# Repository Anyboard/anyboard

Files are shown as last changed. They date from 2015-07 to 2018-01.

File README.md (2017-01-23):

# Anyboard: A platform for making and play hybrid board games

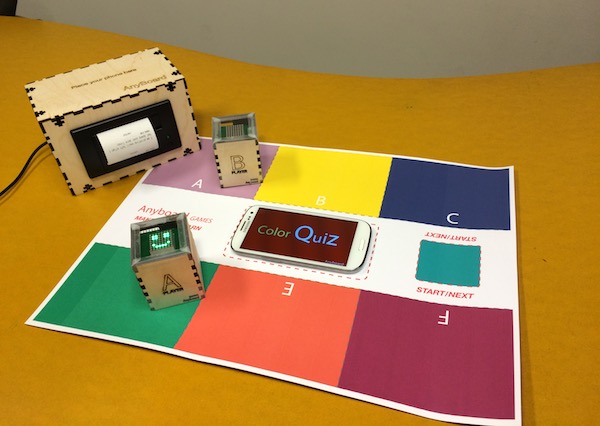
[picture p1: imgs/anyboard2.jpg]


Making hybrid board games that mix the interactivity of video games with the social impact of board games is challenging. While the design process needs to take into account elements from the digital and analog domains, building prototypes requires dealing with diverse technologies in the field of Tangible Interfaces and Interactive Tabletop and Surfaces. 

*Anyboard* is an innovative platform to make and play hybrid board games. Anyboard games blend the social impact of traditional board games with the interactivity of video games. 

Our platform provides theoretical tools to map traditional board game interaction to the hybrid medium and lightweight technology tools to facilitate game prototyping. Our platform provides augmented game pieces that work with traditional cardboards, allowing designers to easily build collaborative interactive games without requiring engineering skills.

For furter references and details please read:
S. Mora, T. Fagerbekk, M. Monnier, E. Schroeder and M. Divitini. “Anyboard: a Platform for Hybrid Board Games”. In proceedings of the International Conference on Entertainment Computing (ICEC), 2016. [preprint](https://dl.dropboxusercontent.com/u/4495822/Papers/Papers/Anyboard_ICEC_preprint.pdf)

Anyboard is released under [Apache 2.0 license](https://tldrlegal.com/license/apache-license-2.0-(apache-2.0)).

# Anyboard fundamentals

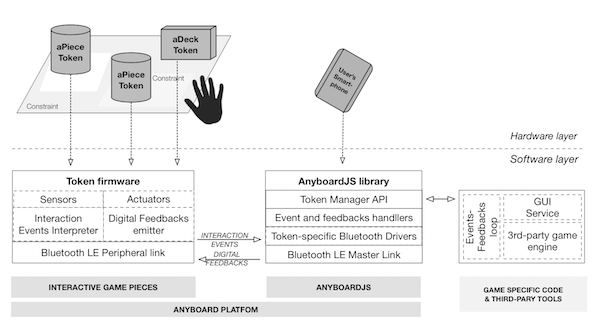
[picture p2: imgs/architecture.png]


The platform supports the development of interactive board games with design and prototyping tools. 

- Anyboard *Design Entities* help modelling players' interaction with technology-augmented game pieces, facilitating mapping game rules with mechanics and helping the transition between design and implementation. 
- Anyboard software and hardware tools support prototype development with 
  1. *Interactive game tokens and cardboard templates* to support the construction of the game hardware. The tokens are generic enough to be reused across different games
  2. *AnyboardJS* A software library to facilitate the coding of games by abstracting the complexity of dealing with hardware and lowlevel programming. The library is designed to be packaged as smartphone app. Rather than being a primary means of interaction, in our platform the smartphone runs the game engine and provide an administration interface. 
  
## Design entities
  
Anyboard Design entities constitute the foundation of a language to model interaction styles with hybrid board games. They are derived from the [ITo approach](http://link.springer.com/chapter/10.1007/978-3-319-26005-1_10) and are mapped to traditional board game elements.

| Anyboard Design Entities | Traditional Board Game Elements |
|:---:|:---:|
| Tokens | Game Pieces |
| Constraints | Board tiles or sockets |
| Interaction Events | Player's actions |

- *Tokens* are technology-augmented artifacts which resemble traditional game pieces; ranging from elements of chance (e.g. an augmented dice in *Backgammon* or RFID-enabled cards in *Monopoly*) to game pieces, e.g. pawns augmented with an LCD displaying the player’s rank in the game.
- *Constraints* are either visual or physical confining regions in the board space. The association or dissociation of a token within a constraint can be mapped to digital operations to activate game dynamics. Examples of constraints are checks for Chess pieces and territories in Risk.
- *Interaction events* are player-triggered manipulations of tokens, that mod- ify the (digital and physical) state of a game. We define three types of events:
  * *Token Event (TE)*: the manipulation of a single token on, over around the board; e.g. the action of rolling a dice or drawing a card
  * *Token-Constraint Event (TCE)*: the operation of building transient token- constraint associations by adding or removing tokens to a constrained region of the board; e.g. moving army pieces beyond a territory line as an attack action
  * *Token-Token Event (TTE)*: the operation of building transient token-token adjacency relationships, achieved by moving tokens on the board; e.g. moving a token next to another token to exchange a resource between two players.

An Anyboard game can be therefore defined as a sequence of player-initiated interaction events that modify spatial configurations of tokens with respect to board constraints and other tokens. As a consequence tokens’ intangible (digital feedbacks) representations are updated.
Sequences of interaction events describe players’ actions during the game and are mapped to specific game dynamics implemented in a game engine.
The game engine connects and exchange data with tokens using the AnyboardJS library running on the user’s smartphone, for example activating specific game mechanics according with interaction events sensed by tokens or triggering digital feedbacks.

## Intearactive game tokens and cardboard template

Anyboard currently prototypes two different types of interactive tokens: aPawn, an augmented game piece, and aDeck, an augmented card deck. Being two of the most common elements of board game they can be used to implement a wide range of games.

### anyPawn

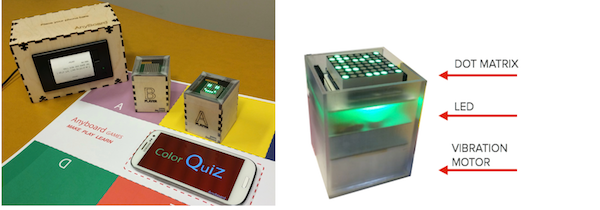
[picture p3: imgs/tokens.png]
aPawn


*aPawns* are a technology-augmented version of pawn pieces commonly found in most games. They are capable of capturing the set of interaction events and produce digital feedbacks. More information: [anyPawn page](./anypawn).

### anyDeck

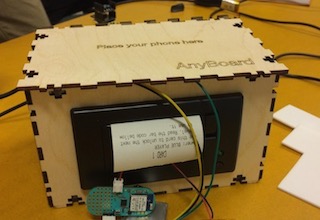
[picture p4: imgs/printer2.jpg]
aDeck


*aDeck* is an interactive version of the card deck commonly found in board games. Instead of holding stacks of cards, aDeck prints out its own cards using a small thermal printer. More information: [anyDeck page](./anydeck)

### Cardboard templates

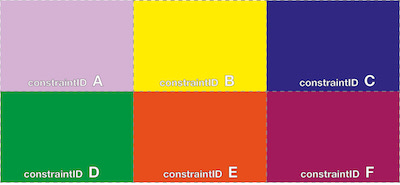
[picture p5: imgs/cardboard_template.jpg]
cardboard_template


The cardboard template provides support to create custom cardboards that interact with aPawn tokens. aPawns use color temperature sensing to implement constraint regions. We therefore selected nine colors that provided satisfactory sensor recognition rate across different materials and printing techniques and associate them with unique IDs to be used in game development. A color palette to draw cardboard with custom constraint regions is provided as a template file that can be modified with vector graphic editors. More information: [Cardboard templates](./cardboard-templates)

## AnyboardJS library

AnyboardJS library is a javascript library providing developer-friendly interface between the interactive tokens pand game-specific code developed with or without third-party game engines and running in a smartphone app. 

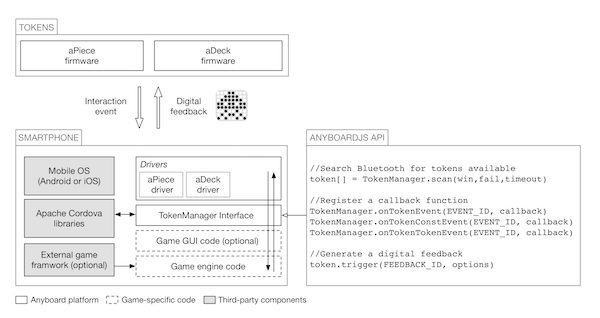
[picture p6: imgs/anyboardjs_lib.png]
AnyboardJS


AnyboardJS provides two main functions. 

1. It establishes wireless links with aPawn and aDeck enabling data exchange using specific drivers for each type of token. 
2. It provides a TokenManager interface to enable developers to easily write javascript code to handle interaction events from tokens and generate digital feedbacks, to implement game-specific routines. The library is designed to be extensible, support to new interactive tokens can be added by writing driver modules. 

Although tokens are the primary user interface with a game, it is possible to code a secondary GUI to display extended informaion and controls on the smartphone screen; e.g. to be used to edit game settings, to display game rules and leader-boards. This functionality can be implemented with external libraries (e.g. jQuery mobile1).

A subset of the TokenManager interface functions is provided in Figure. More information: [AnyboardJS page](./anyboardJS)

# How to make an Anyboard Game

TBD

# Example games

See [Games page](./games).

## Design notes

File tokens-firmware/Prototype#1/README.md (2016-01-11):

## Token Specs Prototype#1

### Pawn

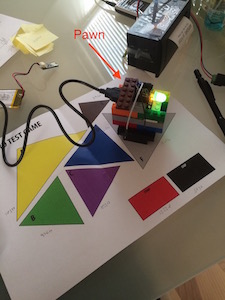
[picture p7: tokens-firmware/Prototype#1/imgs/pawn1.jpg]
pawn front pawn 1

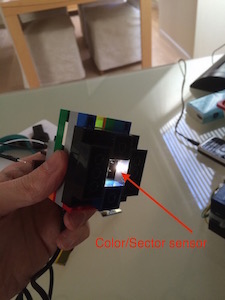
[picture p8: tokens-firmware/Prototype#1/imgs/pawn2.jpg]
pawn front pawn 2


#### Hardware
* [RFDUINO](http://www.rfduino.com)
* RGB Color Sensor - [specs](https://www.adafruit.com/products/1356) - [tutorial](https://learn.adafruit.com/adafruit-color-sensors) 
* RGB LED
* 850Mha LiPo Battery

#### Software
* Arduino IDE
* Arduino JSON - [link](https://github.com/bblanchon/ArduinoJson)
* Color Sensor Library - [link](https://github.com/adafruit/Adafruit_TCS34725)

### Printer

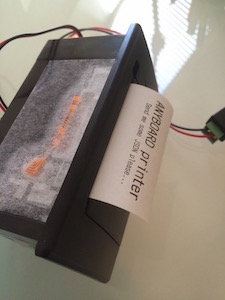
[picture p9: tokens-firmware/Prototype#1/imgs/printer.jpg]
printer front


#### Hardware
* [Bean](http://legacy.punchthrough.com/bean/) *Temporaney, this will be replaced by RFDUINO*
* Mini Thermal Printer - [specs](https://www.adafruit.com/products/597) - [tutorial](https://learn.adafruit.com/mini-thermal-receipt-printer)
* Power adapter

#### Software
* Arduino IDE
* Arduino JSON - [link](https://github.com/bblanchon/ArduinoJson)
* Adafruit Thermal_Library - [link](https://github.com/adafruit/Adafruit-Thermal-Printer-Library)

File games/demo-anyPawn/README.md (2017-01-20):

# Anyboard Demo App

Demonstrates the basic functioning of the Anyboard Pawn and Printer

## Setup

### Required hardware

- Anybaord Pawn

### Download and install Evothings
- Install [Evothings](https://evothings.com/download/) on your PC/Mac
- Install [Evothings](https://evothings.com/download/) app on your phone.

### Connect to Evothings
- Open Evothing on your PC
- Drag the index.html file into [Evothings](http://evothings.com) workbench.
- Open Evothings app on your phone
- Connect to workbench running on PC
- Run the example app from Evothings Workbench

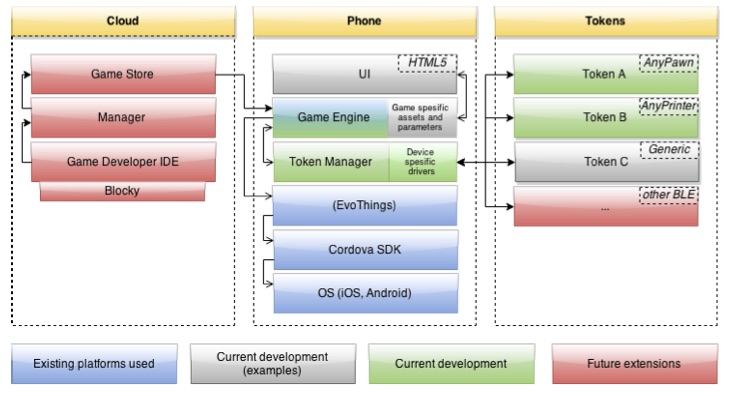
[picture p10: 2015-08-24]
tokens-firmware/Prototype#1/imgs/architecture.jpg

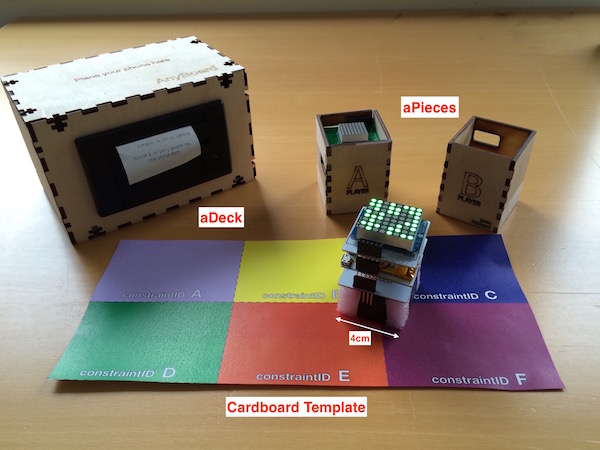
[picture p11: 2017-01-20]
imgs/anyboard.jpg

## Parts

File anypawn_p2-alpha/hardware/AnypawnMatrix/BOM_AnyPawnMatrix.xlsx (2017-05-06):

Bill Of Materials for
Design Title |  |  | AnyPawMatrix
Author |  |  | Théo HYVON
Document Number |  |  | 1
Revision |  |  | 1
Design Created |  |  | vendredi 31 mars 2017
Design Last Modified |  |  | mardi 4 avril 2017
Total Parts In Design |  |  | 6
 |  |  |  |  |  |  |  | Totals
Category | Quantity | References | Value | PCB Package | Fournisseur | Prix | Réf. Fournisseur | Category | Quantity
Condensateurs | 1 | C1 | 220nF | 0603 | Mouser | 0,17 | 581-06036C224MAT2A | Condensateurs | 1
Résistances | 2 | R1-R2 | 10k | 0805 | X | X | X | Résistances | 2
Circuits integrés | 1 | U1 | KWM-30881 | KWM-30881 | Mouser | 4,67 | 485-1623 | Circuits integrés | 2
Circuits integrés | 1 | U2 | HT16K33 | SOP24 |  |  |  | Connecteurs | 1
Connecteurs | 1 | J3-Female | SWD_STM32 CONNECT | SWD_STM32 CONNECT | Mouser | 0,24 | 710-653005113322
Connecteurs | 1 | J3 | SWD_STM32 CONNECT | SWD_STM32 CONNECT | Mouser | 1,8 | 710-653105124022
 |  |  |  |  |  |  |  | Total | 6

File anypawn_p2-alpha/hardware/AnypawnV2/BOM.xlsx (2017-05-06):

Bill Of Materials for AnyPawn
Design Title |  |  | AnyPawn |  | Total Price | 68.00 €
Author |  |  | Théo HYVON
Document Number
Revision |  |  | 1.0
Design Created |  |  | lundi 20 mars 2017
Design Last Modified |  |  | mardi 4 avril 2017
Total Parts In Design |  |  | 95
 |  |  |  |  |  |  |  |  | Totals
Category | Quantity | References | Value | PCB Package | Fournisseur | Prix | Réf. Fournisseur |  | Category | Quantity
Condensateurs | 8 | C1-C8 | 1nF | 0805 | Mouser | 0,885 | 767-0805B102J102NT | 7.08 € | Condensateurs | 25
Condensateurs | 5 | C10,C14,C16-C17,C24 | 10uF | 0805 | Mouser | 0,141 | 81-GRM219R60J106KE9D | 0.70 € | Circuits integrés | 11
Condensateurs | 3 | C9, C11, C12 | 220nF | 0603 | Mouser | 0,17 | 581-06036C224MAT2A | 0.51 € | Diodes | 7
Condensateurs | 7 | C13,C15,C18-C20,C23,C25 | 100nF | 0603 | Mouser | 0,094 | 81-GRM188R70J104KA1D | 0.66 € | Inductances | 7
Condensateurs | 2 | C21-C22 | 47pF | 0402 | Mouser | 0,141 | 581-06036A470JAT2A | 0.28 € | Miscellaneous | 15
Résistances | 4 | R1,R5,R9,R13 | 220k | 0603 | Mouser | 0,104 | 755-ESR03EZPF2203 | 0.42 € | Total | 95
Résistances | 5 | R2,R6,R10,R14,R21 | 1k | 0603 | Mouser | 0,104 | 755-KTR03EZPJ102 | 0.52 €
Résistances | 13 | R3-R4,R7-R8,R11-R12,R15-R17,R19-R20,R22,R29 | 10k | 0603 | Mouser | 0,104 | 755-ESR03EZPF1002 | 1.35 €
Résistances | 1 | R18 | 100 | 0603 | Mouser | 0,179 | 71-CRCW0603100RFKEAH | 0.18 €
Résistances | 2 | R23-R24 | 27 | 0402 | Mouser | 0,094 | 667-ERJ-2RKF27R0X | 0.19 €
Résistances | 3 | R25-R26,R28 | 510 | 0603 | Mouser | 0,095 | 652-CR0603FX-5100ELF | 0.29 €
Résistances | 1 | R27 | 2k | 0603 | Mouser | 0,094 | 71-CRCW0603-2.0K-E3 | 0.09 €
Résistances | 1 | R31 | 47k | 0603 | Mouser | 0,113 | 755-KTR03EZPF4702 | 0.11 €
Circuits integrés | 2 | U1-U2 | LM358 | TSSOP8 | Mouser | 0,349 | 511-LM358DT | 0.70 €
Circuits integrés | 1 | U3 | CY8C4245LQI-483 | CY-QFN40-6X6-NOCP | Mouser | 3,17 | 727-CY8C4245LQI-483 | 3.17 €
Circuits integrés | 1 | U4 | TCS34725 | TCS32725 | Mouser | 2,49 | 985-TCS34725FN | 2.49 €
Circuits integrés | 1 | U5 | VL6180X | VL6180X | Mouser | 4,49 | 511-VL6180XV0NR/1 | 4.49 €
Circuits integrés | 1 | U6 | TPS63001 | PVSON-N10 | Mouser | 2,12 | 595-TPS63001DRCR | 2.12 €
Circuits integrés | 1 | U7 | TPS79028 | SOT95P280X145-5A | Mouser | 1,25 | 595-TPS79028DBVR | 1.25 €
Circuits integrés | 1 | U8 | FTD231X | QFN-20 | Mouser | 2 | 895-FT231XQ-R | 2.00 €
Circuits integrés | 1 | U9 | MCP73831 | SOT23-5 | Mouser | 0,566 | 579-MCP73831T-2ACIOT | 0.57 €
Circuits integrés | 1 | U10 | SIMBLEE | SIMBLEE | Mouser | 17,11 | 975-RFD77101 | 17.11 €
Circuits integrés | 1 | U11 | LSM9DS0 | LGA-24 4X4X1MM | Digikey | 6,87 | 497-13902-1-ND | 6.87 €
Diodes | 1 | D1 | CLM3C-WKW-CWBYA453 | CREE_LED_WHITE | Mouser | 0,198 | 941-CLM3CWKWCWBYA453 | 0.20 €
Diodes | 1 | D2 | ESDALC6V1 | 0402 ORIENTED | Mouser | 0,453 | 511-ESDALC6V1-1M2 | 0.45 €
Diodes | 1 | D3 | LED_CMS | LEDC1608X60 | Mouser | 0,339 | 720-LGQ396A3964 | 0.34 €
Diodes | 1 | D4 | LED_CMS | LEDC1608X60 | Mouser | 0,189 | 755-SML-D12U1WT86 | 0.19 €
Diodes | 1 | D5 | LED_CMS | LEDC1608X60 | Mouser | 0,33 | 755-SMLE13BC8TT86 | 0.33 €
Diodes | 1 | D6 | 1N4148WS-7 | SOD2514X100 | Mouser | 0,16 | 621-1N4148WS-F | 0.16 €
Diodes | 1 | D7 | NEOPIXEL SK6812 | NEOPIXEL | Mouser | 4,24 | 485-1655 | 4.24 €
Inductances | 4 | L1-L4 | 330uH | IND_5.8_BOURNS | Mouser | 0,445 | 652-SDR0604-221KL | 1.78 €
Inductances | 1 | L5 | 2.2uH | IND_ASPI2512 | Mouser | 0,358 | 815-ASPI25122R2MT2 | 0.36 €
Inductances | 2 | L6-L7 | LI0402E300R-10 | 0402 | Mouser | 0,1 | 875-LI0402E300R-10 | 0.20 €
Miscellaneous | 1 | J1 | USBCONN | CONN USB B MICRO | Mouser | 0,868 | 490-UJ2-MIBH2-4-SMT | 0.87 €
Miscellaneous | 1 | J2 | SIL-100-02 | CONN-SIL2 | X | 0 | X | 0.00 €
Miscellaneous | 1 | J3 | CONN-SIL5 | CONN-SIL5 | X | 0 | X | 0.00 €
Miscellaneous | 1 | J4-Female | JX | SWD_STM32 CONNECT | Mouser | 0,24 | 710-653005113322 | 0.24 €
Miscellaneous | 1 | J4 | JX | SWD_STM32 CONNECT | Mouser | 1,8 | 710-653105124022 | 1.80 €
Miscellaneous | 1 | J5 | Battery | CONN-SIL2 | X | 0 | X | 0.00 €
Miscellaneous | 5 | Q1-Q4,Q7 | BC847B | SOT23 | Mouser | 0,151 | 757-TBC847BLM | 0.76 €
Miscellaneous | 2 | Q5-Q6 | BSS138 | SOT23 | Mouser | 0,198 | 512-BSS138 | 0.40 €
Miscellaneous | 1 | SW1 | 506-MLL1200S | SPDT SLIDE SWITCH | Mouser | 2,17 | 506-MLL1200S | 2.17 €
Miscellaneous | 2 | VR1-VR2 | CG0402MLA-5.5MG | 0402 | Mouser | 0,189 | 652-CG0402MLA-5.5MG | 0.38 €

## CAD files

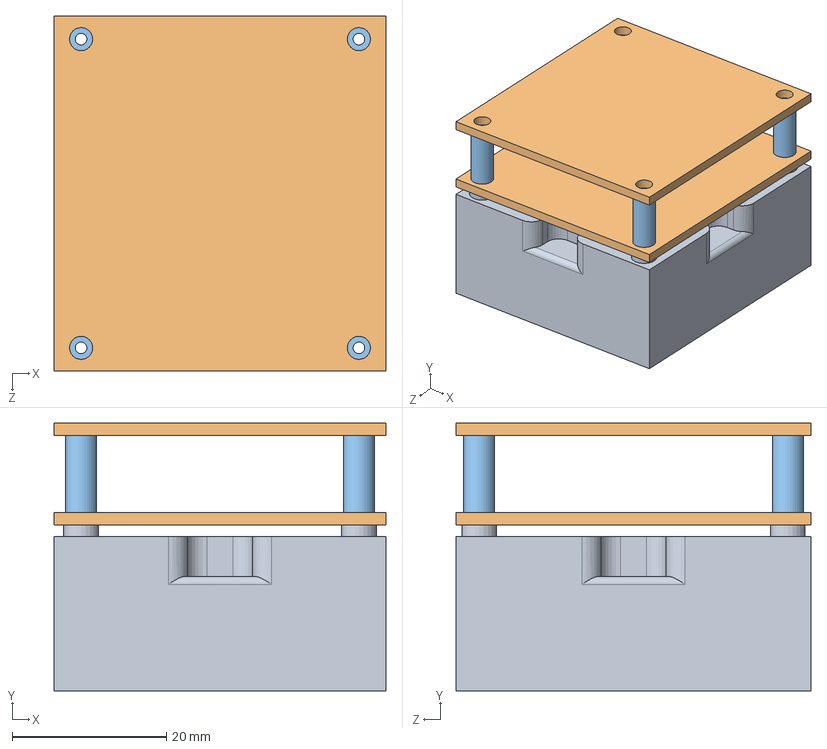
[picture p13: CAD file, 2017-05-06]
anypawn_p2-alpha/case/Assemblage.SLDASM
43.0 x 34.7 x 46.0 mm
Footer
Board x 2
Spacer x 4

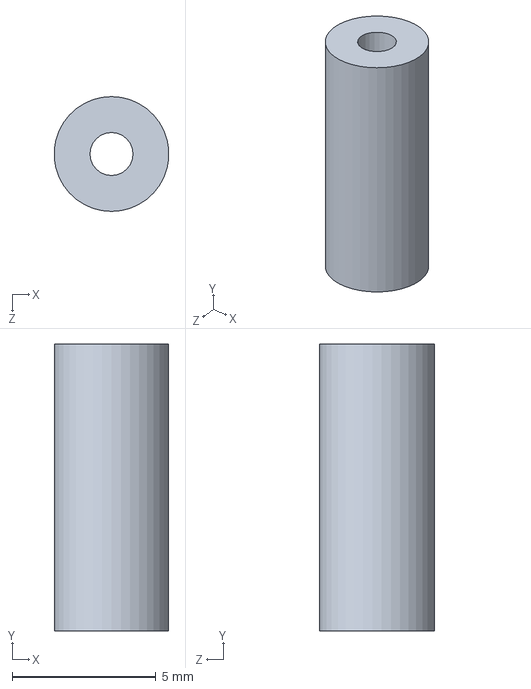
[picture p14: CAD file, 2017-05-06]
anypawn_p2-alpha/case/Spacer.SLDPRT
3.99 x 10.0 x 4.00 mm

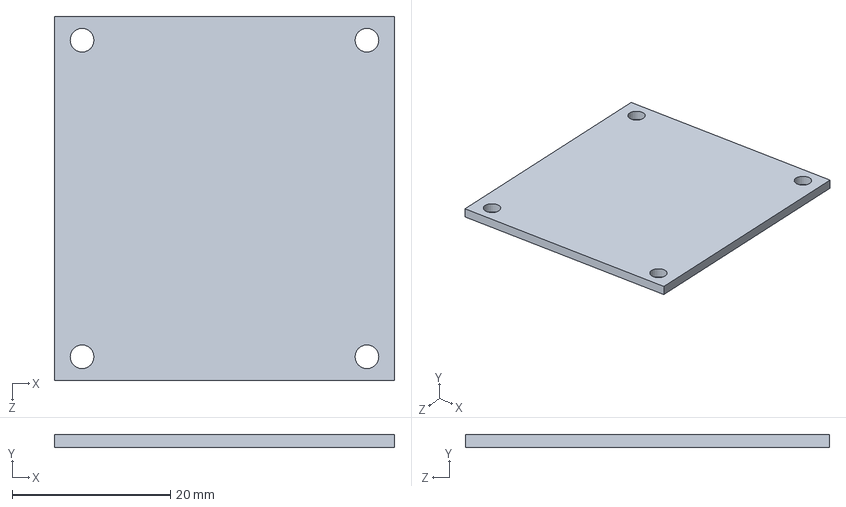
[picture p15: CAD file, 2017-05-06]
anypawn_p2-alpha/case/Board.SLDPRT
43.0 x 1.60 x 46.0 mm

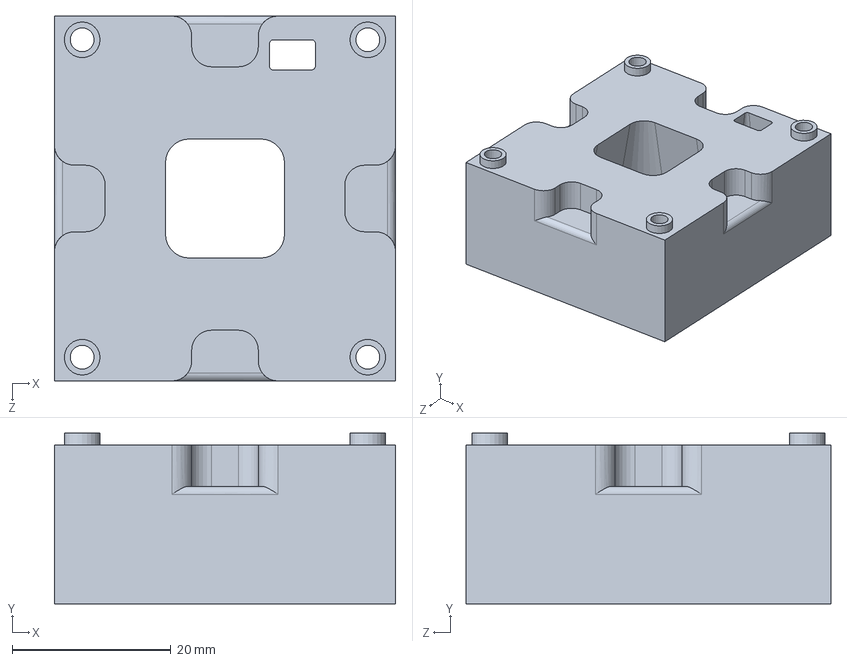
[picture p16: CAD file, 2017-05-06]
anypawn_p2-alpha/case/Footer.SLDPRT
43.0 x 21.5 x 46.0 mm

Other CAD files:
anypawn_p2-alpha/case/Spacer2.SLDPRT
anypawn_p2-alpha/case/Footer.STL

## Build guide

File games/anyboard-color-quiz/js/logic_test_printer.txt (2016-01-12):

var logic = {
    initiate: function() {
        var handleTokenMove = function(token, constraint, options) {
            AnyBoard.Logger.log(token.player + " moved to tile " + constraint);
            token.player.location = constraint;

            if (logic.everyOneHasAnswered()) {
                ui.showAnswer();
                return;
            }

            // If the token is the only one, we will not expect any Token-Token events to occur before all (1) token
            // is placed on a tile. Therefore we check if the token is the only one, and trigger the TT-event manually
            // if it is
            if (logic.numberOfConnectedTokens() === 1 && token.player.location === 2) {
                handleTokenTokenTouch(token, token);
            }
        };

        var handleTokenTokenTouch = function(initiatingToken, respondingToken, options) {
            if (respondingToken.player.location === 2) {
                hyper.log("handleTokenTokenTouch");
                if (typeof d.currentQuestionPos === "undefined") ui.activatePanel('game');
                else ui.nextQuestion();
            }
        };

        logic.addListener("game", logic.startGame);
        logic.addListener("summary", ui.finishGame);

        AnyBoard.TokenManager.onTokenConstraintEvent("MOVE_TO", handleTokenMove);
        AnyBoard.TokenManager.onTokenTokenEvent("MOVE_NEXT_TO", handleTokenTokenTouch)
    },

    // Discover bluetooth tokens in proximity
    discover: function() {
        var self = this;
        AnyBoard.TokenManager.scan(
            // success function to be executed upon _each_ token that is discovered
            function(token) {
                self.addDiscovered(token);
            },
            // function to be executed upon failure
            function(errorCode) {
                hyper.log(errorCode)
            }
        );
    },

    // Function to be executed upon having discovered a token
    addDiscovered: function(token) {
        if (!d.devices[token.address]) {
            d.devices[token.address] = token;

			if(token.name === "RFduino") {
				// Add button for token to body
				$('#setup').append('<div class="token center"><button type="button" id="' + token.address +
				'" onclick="logic.connect(' + "'" + token.address + "'" +
				')" class="grey token">' + token.name + ' </button>' +
				'<button class="player-icon' + '">&nbsp;</button>' + '</div>');

				// Add listener to be executed if the token connects
				token.on('connect', function() {
						document.getElementById(token.address).className = 'green token';
						token.color = d.colors.pop();
						token.player = new AnyBoard.Player(
							token.color + "-player",
							{
								"color": token.color,
								"points": 0,
								"locations": -1,
								"token": token
							}
						);
						d.players.push(token.player);
						$(document.getElementById(token.address)).next().addClass(token.color);
						token.ledOn(token.color);
				});

				// Add listener to be executed if the token disconnects
				token.on('disconnect', function() {
					document.getElementById(token.address).className = 'grey token';
					$(document.getElementById(token.address)).next().removeClass(token.color);
					d.colors.push(token.color);
				})
			}
			else
			{
				// Add button for token to body
                document.body.innerHTML += '<div class="token center"><button type="button" id="' + token.address + '" onclick="logic.connect(' + "'" + token.address + "'" + ')" class="grey token">' + token.name + ' </button><br />' + '</div>';

                // Add listener to be executed if the token connects
                token.on('connect', function() {
                    document.getElementById(token.adress).className = 'green token';
                });

                // Add listener to be executed if the token disconnects
                token.on('disconnect', function() {
                    document.getElementById(token.adress).className = 'red token';
                })
			}
        }
    },

    // Attempts to connect to token.
    connect: function(tokenAddress) {
        var token = d.devices[tokenAddress];

		if(token.name === "RFduino") {
			// If already connecting, stop
			if (document.getElementById(tokenAddress).className.indexOf('blue') !== -1)
				return;

			// If already connected, disconnect
			if (document.getElementById(tokenAddress).className.indexOf('green') !== -1) {
				token.disconnect();
				return;
			}
			// Signal that we're attempting to connect
			document.getElementById(tokenAddress).className = 'blue token';

			// Send connect command.
			token.connect();
		}
		else
		{
			// If already connecting, stop
			if (document.getElementById(tokenAddress).className == 'blue token')
				return;

			// If already connected, attempt to print
			if (document.getElementById(tokenAddress).className == 'green token') {
				this.print(token);
				return;
			}

			// Signal that we're attempting to connect
			document.getElementById(tokenAddress).className = 'blue token';

			// Send connect command. 
			token.connect();
		}
    },

    startGame: function(){
        hyper.log("startGame");
        d.questions = logic.shuffle(d.questions);
        d.currentQuestionPos = -1;
        ui.nextQuestion();
        for (var index in d.players) {
            if (d.players.hasOwnProperty(index))
                d.players[index].points = 0;
        }
    },

    shuffle: function(o){
        for(var j, x, i = o.length; i; j = Math.floor(Math.random() * i), x = o[--i], o[i] = o[j], o[j] = x);
        return o;
    },

    addListener: function(name, callback) {
        if (!d.listeners[name])
            d.listeners[name] = [];
        d.listeners[name].push(callback);
    },

    trigger: function(name, options) {
        hyper.log("trigger: " + name);
        if (d.listeners[name]) {
            for (var i = d.listeners[name].length - 1; i >= 0; i--) {
                d.listeners[name][i](options);
            }
        }
    },

    getCurrentQuestion: function() {
        return d.questions[d.currentQuestionPos];
    },

    getNextQuestion: function() {
        hyper.log("nextQuestion");
        d.currentQuestionPos += 1;
        if (d.currentQuestionPos >= d.questions.length) {
            return undefined; // returns undefined if no more questions left
        }
        return d.questions[d.currentQuestionPos];
    },

    givePoints: function() {
        var question = logic.getCurrentQuestion();
        for (var key in d.players) {
            if (d.players.hasOwnProperty(key)) {
                var player = d.players[key];
                var answer = player.location;
                if (question.alternatives.hasOwnProperty(answer-3)) { // '-3' because yellow = 3, green = 4...
                    if (question.alternatives[answer-3].correct)
                        player.points += 1;
                }
            }
        }
    },

    everyOneHasAnswered: function() {
        var tokenSet = AnyBoard.TokenManager.tokens;
        for (var key in tokenSet) {
            if (tokenSet.hasOwnProperty(key) && tokenSet[key].isConnected()) {
                if (tokenSet[key].player.location < 3) {
                    return false;
                }
            }
        }
        return true;
    },

    numberOfConnectedTokens: function() {
        var tokenSet = AnyBoard.TokenManager.tokens;
        var numOfConnected = 0;
        for (var key in tokenSet) {
            if (tokenSet.hasOwnProperty(key) && tokenSet[key].isConnected()) numOfConnected += 1;
        }
        return numOfConnected;
    },
	
	// Send green led command. Will only work on LightBlue Bean with a certain hardware.
    print: function(token) {
		token.print("##l##SI am printing small left align that spans over more lines##nnewLine##n##ccenter##f##f##f");
    }
};

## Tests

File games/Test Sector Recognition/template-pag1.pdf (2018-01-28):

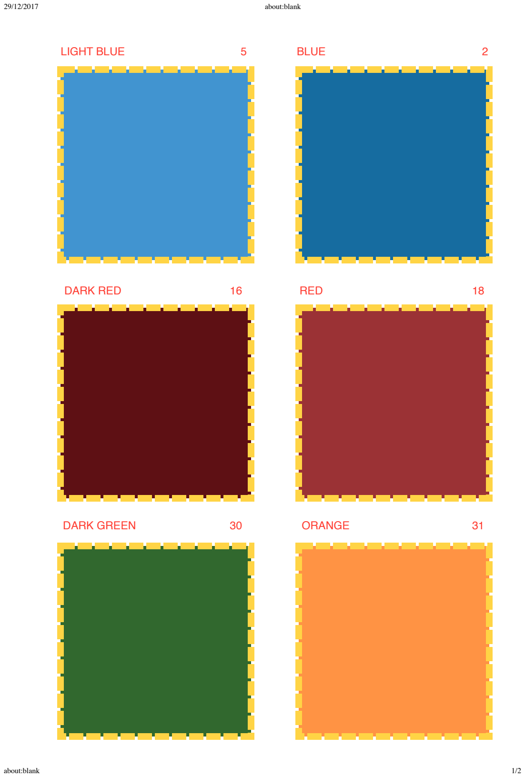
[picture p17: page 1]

29/12/2017 | about:blank
about:blank | 1/2

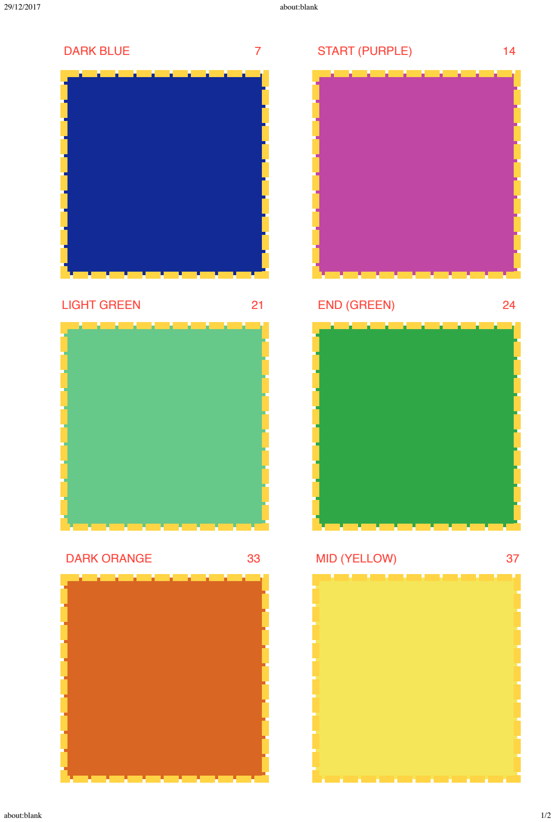
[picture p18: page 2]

29/12/2017 | about:blank
about:blank | 1/2

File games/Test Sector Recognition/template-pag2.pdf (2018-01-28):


29/12/2017 | about:blank
about:blank | 1/2

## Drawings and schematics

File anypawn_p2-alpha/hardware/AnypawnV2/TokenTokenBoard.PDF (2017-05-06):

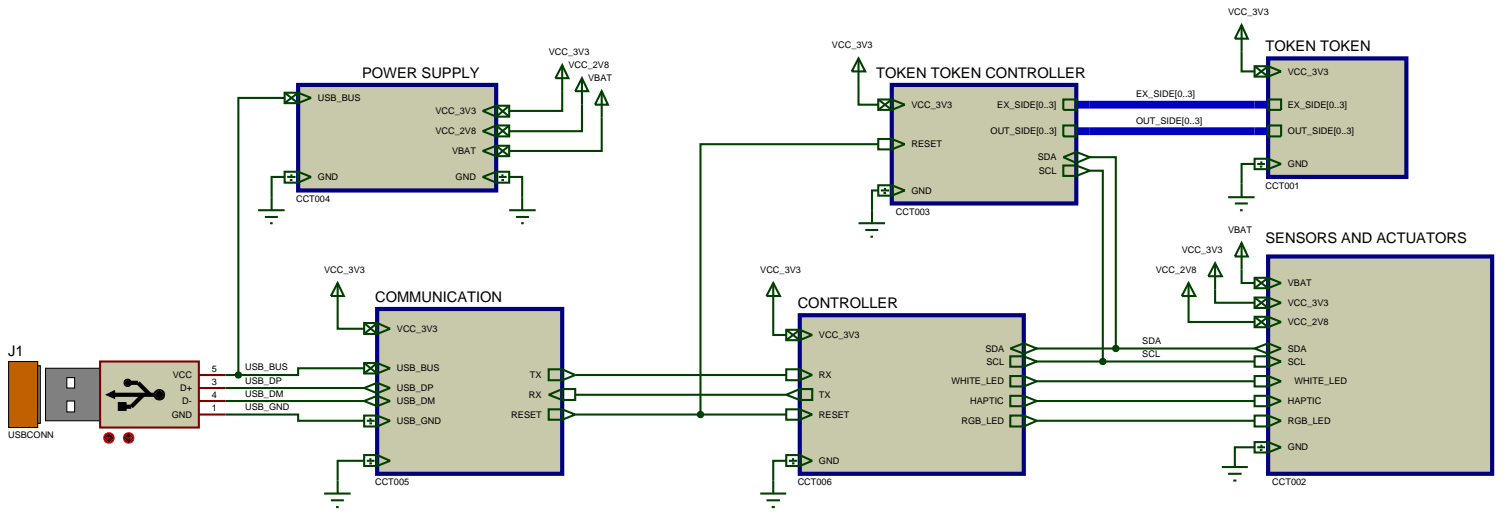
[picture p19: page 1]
Project :; DATE:; PAGE:; AnyPawn; Théo HYVON; REV:; TIME:; Sheet :; Functionnal design; OUT_SIDE[0..3]; EX_SIDE[0..3]; USB_DP USB_DM USB_GND; USB_BUS; SDA SCL; TOKEN TOKEN; CCT001; VCC_3V3; GND; CCT003; POWER SUPPLY; CCT004; CCT002; SCL; SDA; VCC_2V8; VCC_3V3 VCC_2V8; COMMUNICATION; CCT005; USB_DP USB_DM; USB_GND; RESET; VCC; USBCONN; WHITE_LED; CONTROLLER; CCT006; VBAT; HAPTIC; RGB_LED

VCC_3V3
TOKEN TOKEN CONTROLLER

VBAT
SENSORS AND ACTUATORS

U1:A

R1

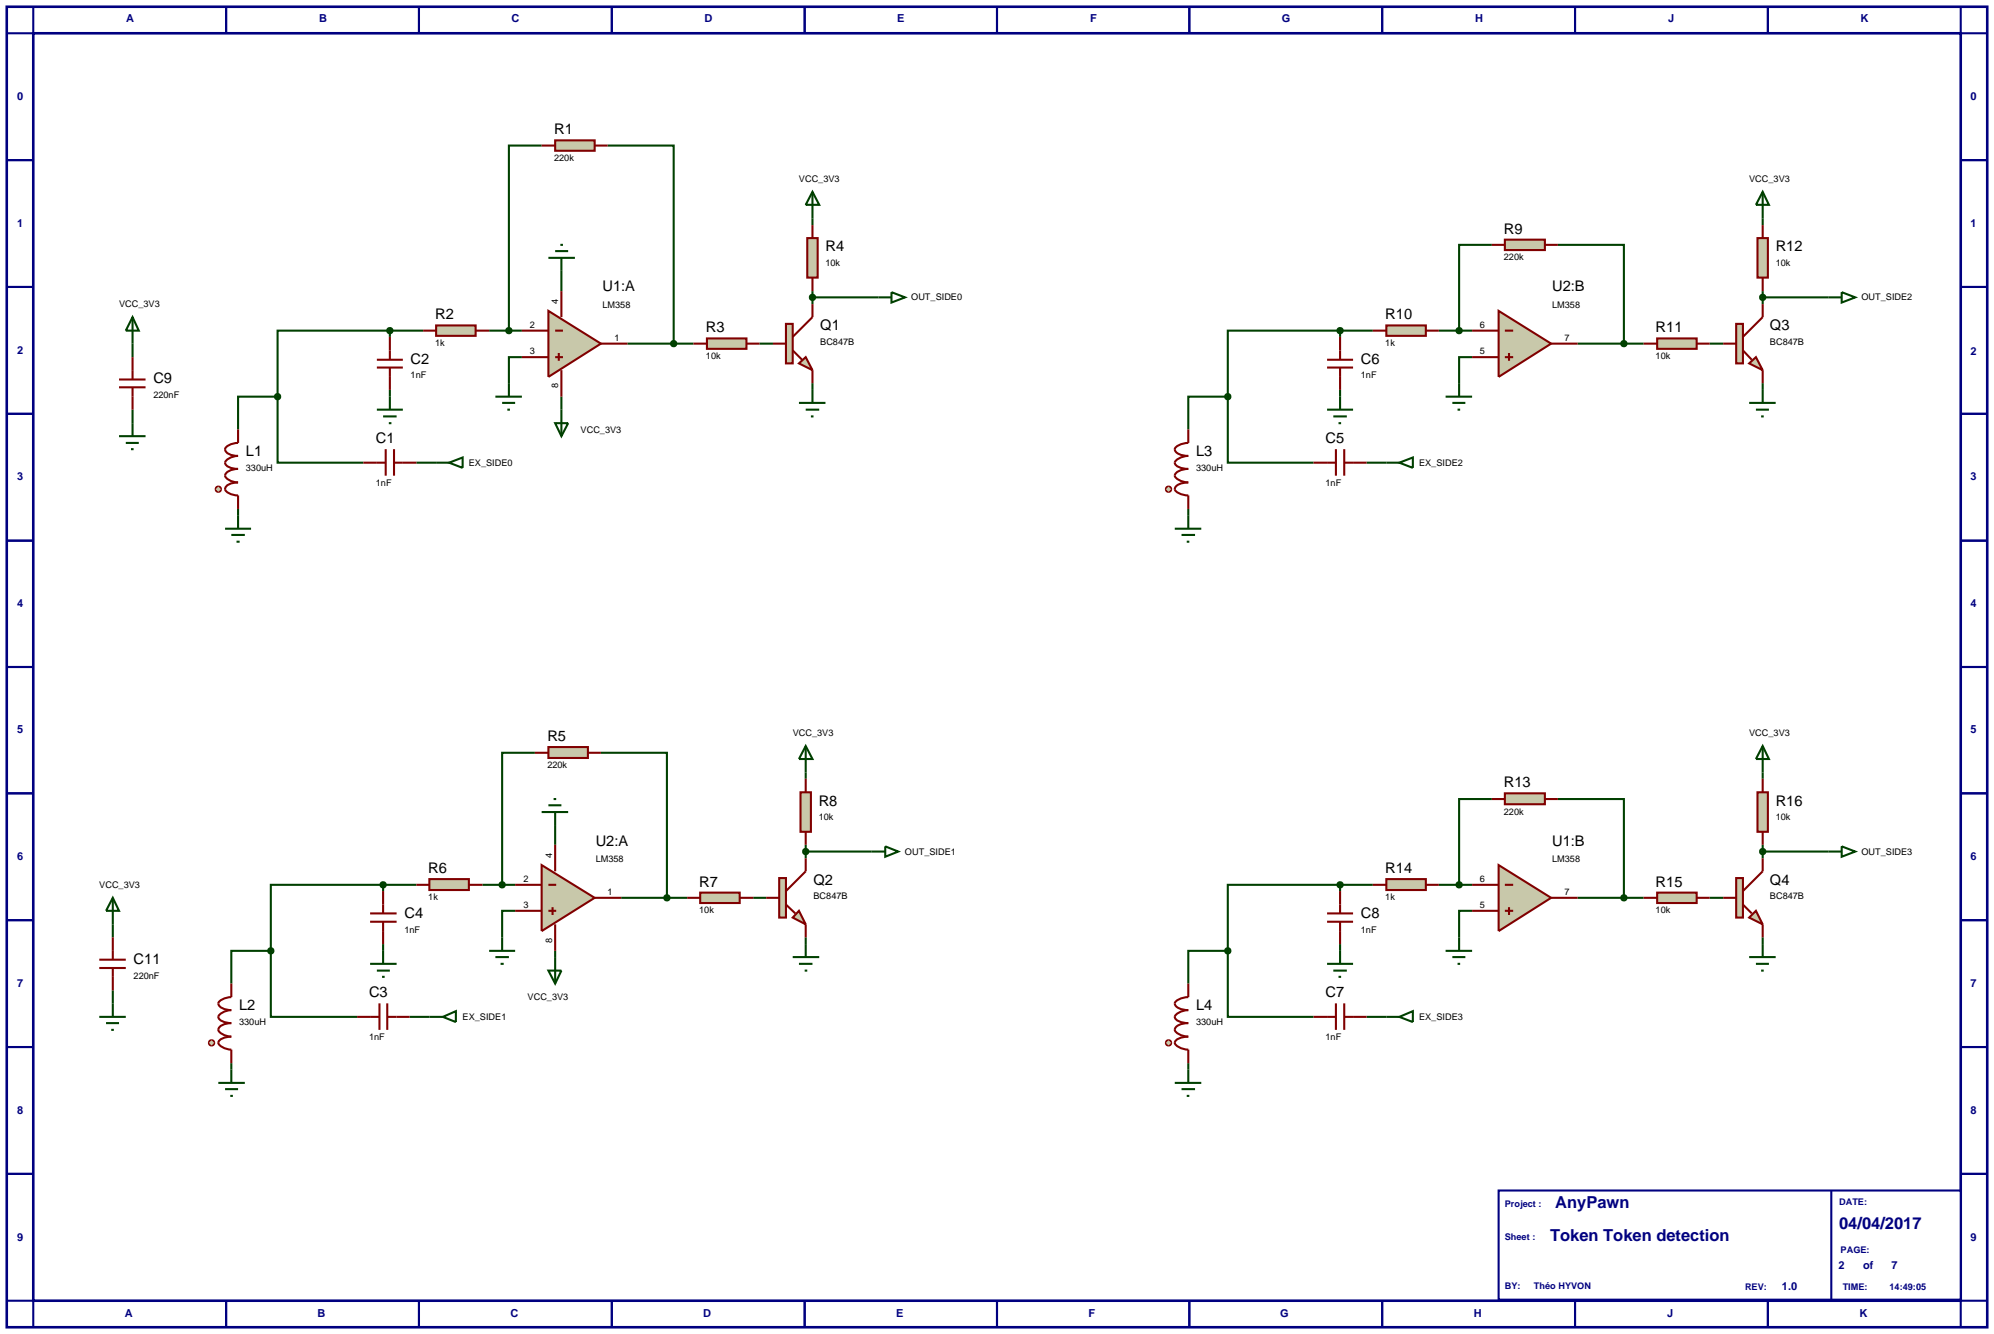
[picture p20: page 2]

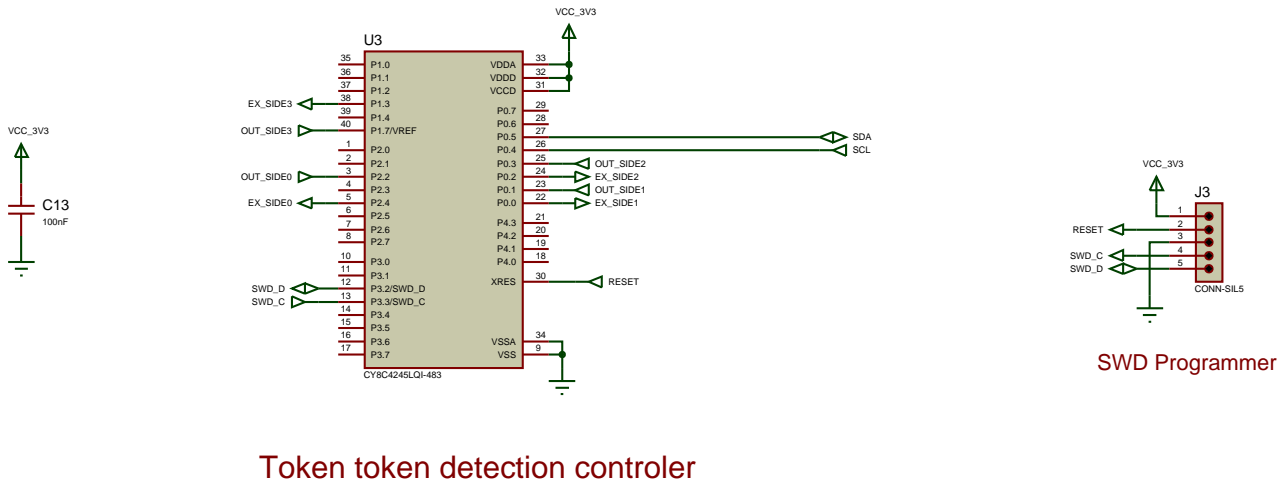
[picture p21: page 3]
Project :; DATE:; AnyPawn; Sheet :; Token Token Controller; P1.7/VREF 40; P3.1 11 P3.2/SWD_D 12 P3.3/SWD_C 13 P3.4 14; VSS; VDDD; VCCD; XRES; VSSA; VDDA; CY8C4245LQI-483; VCC_3V3; SWD_C; SWD_D; RESET; EX_SIDE0; EX_SIDE1; EX_SIDE2; EX_SIDE3; OUT_SIDE0; OUT_SIDE1; OUT_SIDE2; OUT_SIDE3; SDA; SCL; CONN-SIL5; SWD_C SWD_D; SWD Programmer

Token token detection controler

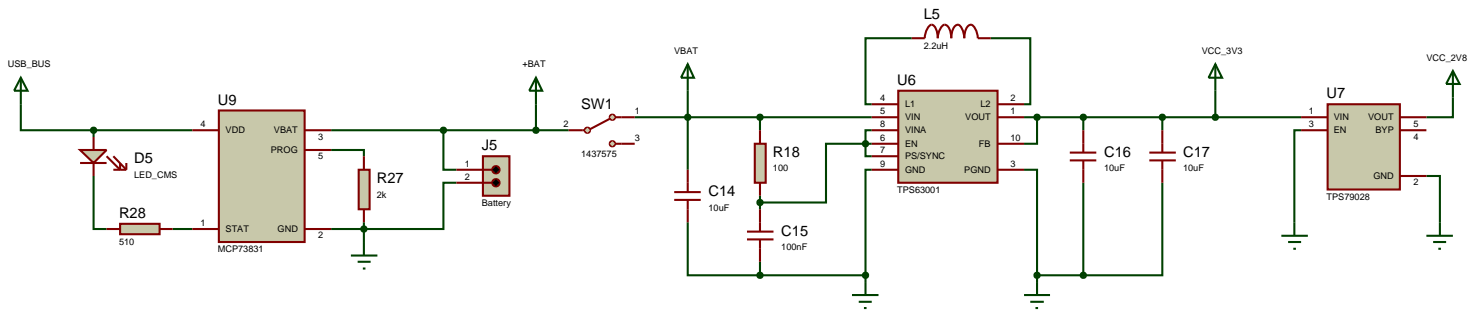
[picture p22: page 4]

U4
U5

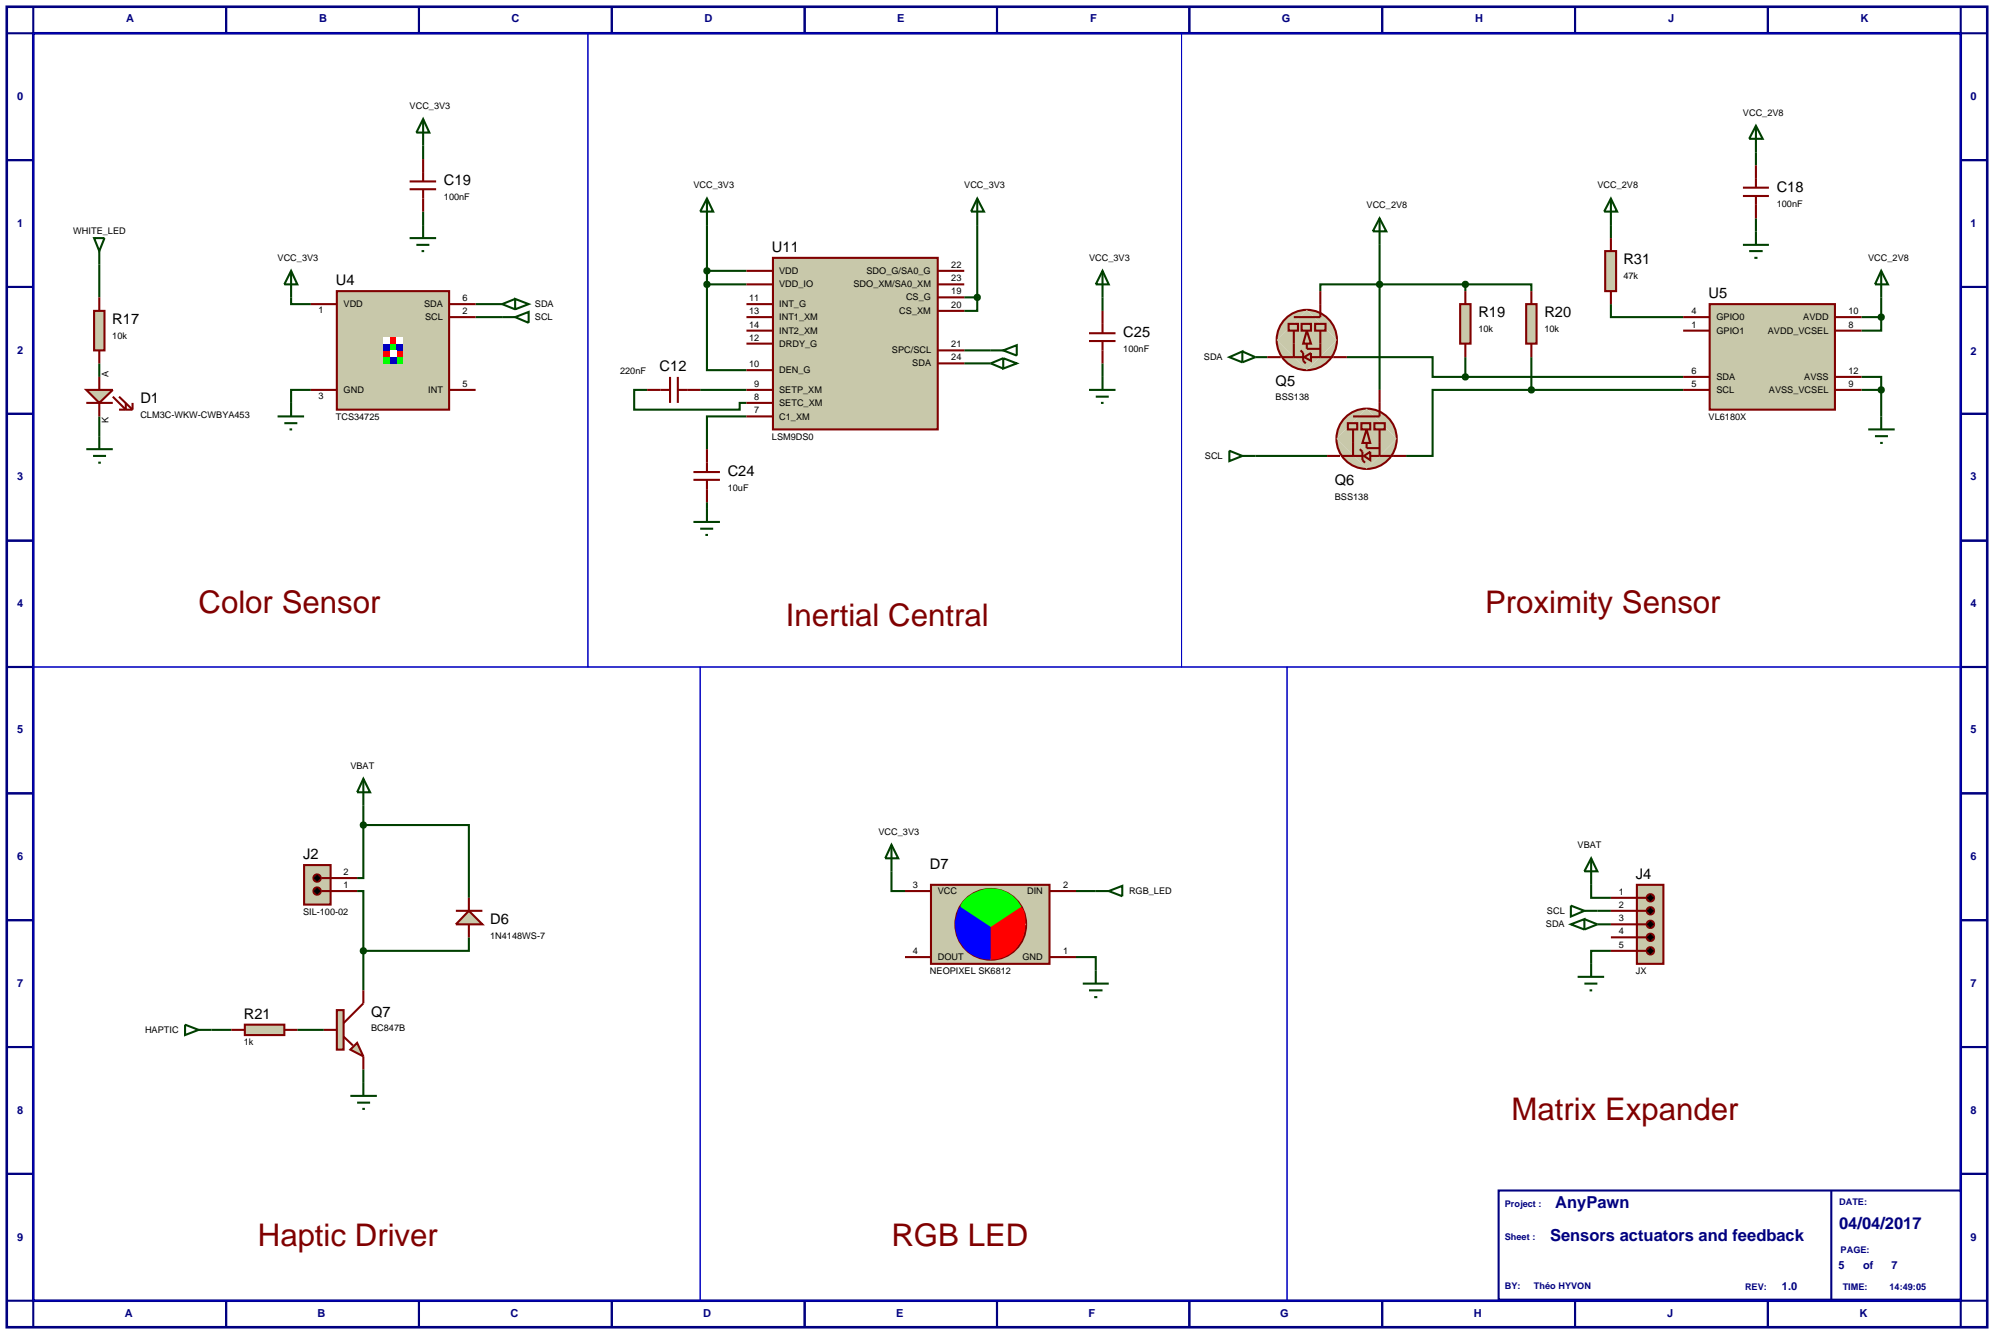
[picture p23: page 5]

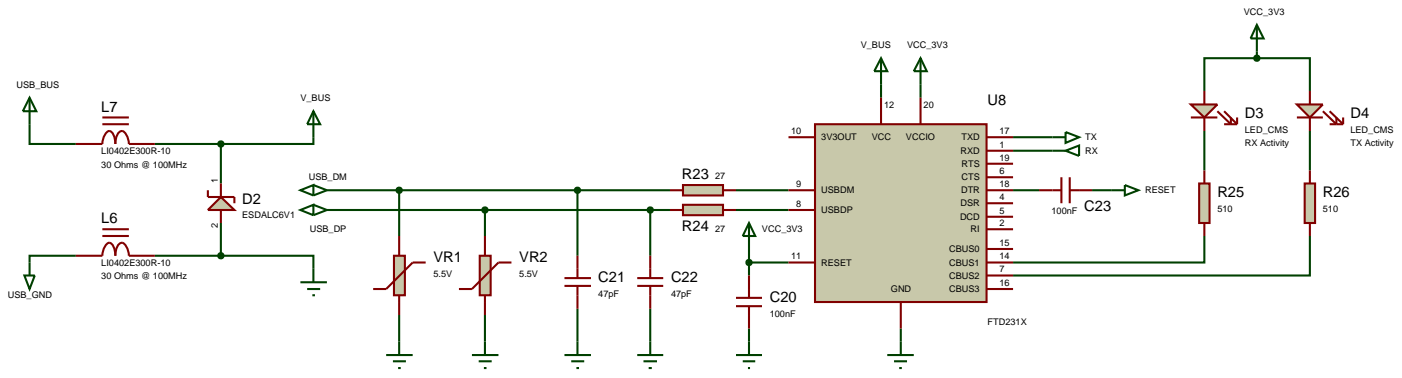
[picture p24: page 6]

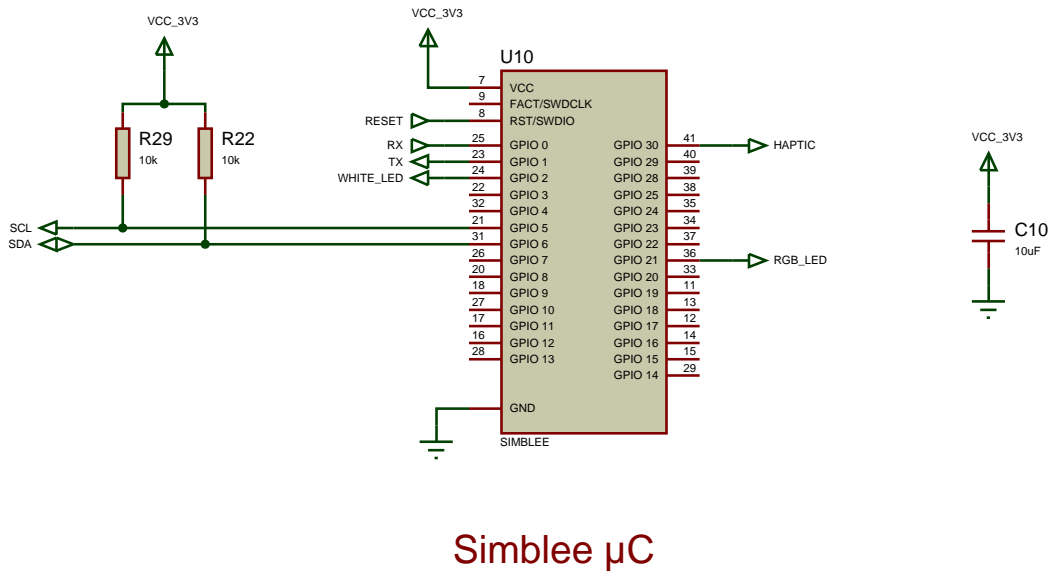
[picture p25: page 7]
Project :; DATE:; AnyPawn; Sheet :; Simblee Controler; VCC_3V3; SDA; SCL; GPIO 0 25 GPIO 1 23 GPIO 2 24 GPIO 3 22 GPIO 4 32 GPIO 5 21 GPIO 6 31 GPIO 7 26 GPIO 8 20 GPIO 9 18 GPIO 10 27 GPIO 11 17 GPIO 12 16; GPIO 30; GPIO 29; GPIO 28; GPIO 25; GPIO 24; GPIO 23; GPIO 22; GPIO 21; GPIO 20; GPIO 19; FACT/SWDCLK 9 RST/SWDIO 8; VCC 7; GND; GPIO 18; GPIO 17; GPIO 16; GPIO 15; GPIO 14; GPIO 13 28; SIMBLEE; RESET; RX TX WHITE_LED; VCC_3V3 HAPTIC; RGB_LED; Simblee µC

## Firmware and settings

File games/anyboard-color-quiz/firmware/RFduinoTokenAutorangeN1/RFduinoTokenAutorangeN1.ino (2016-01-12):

/*
 * AnyBoard Pawn firmware
 * Code based on RFduino (http://www.rfduino.com/) and
 * AdaFruit Color Sensor TCS34725 (https://www.adafruit.com/products/1334)
 *
 * Dependencies: RFduinoBLE.h and Wire.h (https://github.com/RFduino/RFduino)
 *               Adafruit_TCS34725.h (https://github.com/adafruit/Adafruit_TCS34725)
 *
 * Reference: https://cdn.sparkfun.com/datasheets/Dev/RFduino/rfduino.ble_.programming.reference.pdf
 *
 * The bean parses incoming arrays of uint8 (numbers 0-255) over bluetooth.
 *      [cmd, data, data, data etc...]
 *
 * If the cmd matches one of the COMMANDS specified, it will execute that command and respond back
 * Else it will respond 0 back
 *
 */

#include <RFduinoBLE.h>  //
#include <Wire.h>
#include "Adafruit_TCS34725.h"
#include <string.h>

//************************************************************************************************************************
// some magic numbers for this device from the DN40 application note
#define TCS34725_R_Coef 0.136 
#define TCS34725_G_Coef 1.000
#define TCS34725_B_Coef -0.444
#define TCS34725_GA 1.0
#define TCS34725_DF 310.0
#define TCS34725_CT_Coef 3810.0
#define TCS34725_CT_Offset 1391.0

// Autorange class for TCS34725
class tcs34725 {
public:
  tcs34725(void);

  boolean begin(void);
  void getData(void);  

  boolean isAvailable, isSaturated;
  uint16_t againx, atime, atime_ms;
  uint16_t r, g, b, c;
  uint16_t ir; 
  uint16_t r_comp, g_comp, b_comp, c_comp;
  uint16_t saturation, saturation75;
  float cratio, cpl, ct, lux, maxlux;
  
private:
  struct tcs_agc {
    tcs34725Gain_t ag;
    tcs34725IntegrationTime_t at;
    uint16_t mincnt;
    uint16_t maxcnt;
  };
  static const tcs_agc agc_lst[];
  uint16_t agc_cur;

  void setGainTime(void);  
  Adafruit_TCS34725 tcs;    
};
//
// Gain/time combinations to use and the min/max limits for hysteresis 
// that avoid saturation. They should be in order from dim to bright. 
//
// Also set the first min count and the last max count to 0 to indicate 
// the start and end of the list. 
//
const tcs34725::tcs_agc tcs34725::agc_lst[] = {
  { TCS34725_GAIN_60X, TCS34725_INTEGRATIONTIME_700MS,     0, 47566 },
  { TCS34725_GAIN_16X, TCS34725_INTEGRATIONTIME_154MS,  3171, 63422 },
  { TCS34725_GAIN_4X,  TCS34725_INTEGRATIONTIME_154MS, 15855, 63422 },
  { TCS34725_GAIN_1X,  TCS34725_INTEGRATIONTIME_2_4MS,   248,     0 }
};
tcs34725::tcs34725() : agc_cur(0), isAvailable(0), isSaturated(0) {
}

// initialize the sensor
boolean tcs34725::begin(void) {
  tcs = Adafruit_TCS34725(agc_lst[agc_cur].at, agc_lst[agc_cur].ag);
  if ((isAvailable = tcs.begin())) 
    setGainTime();
  return(isAvailable);
}

// Set the gain and integration time
void tcs34725::setGainTime(void) {
  tcs.setGain(agc_lst[agc_cur].ag);
  tcs.setIntegrationTime(agc_lst[agc_cur].at);
  atime = int(agc_lst[agc_cur].at);
  atime_ms = ((256 - atime) * 2.4);  
  switch(agc_lst[agc_cur].ag) {
  case TCS34725_GAIN_1X: 
    againx = 1; 
    break;
  case TCS34725_GAIN_4X: 
    againx = 4; 
    break;
  case TCS34725_GAIN_16X: 
    againx = 16; 
    break;
  case TCS34725_GAIN_60X: 
    againx = 60; 
    break;
  }        
}

// Retrieve data from the sensor and do the calculations
void tcs34725::getData(void) {
  // read the sensor and autorange if necessary
  tcs.getRawData(&r, &g, &b, &c);
  while(1) {
    if (agc_lst[agc_cur].maxcnt && c > agc_lst[agc_cur].maxcnt) 
      agc_cur++;
    else if (agc_lst[agc_cur].mincnt && c < agc_lst[agc_cur].mincnt)
      agc_cur--;
    else break;

    setGainTime(); 
    delay((256 - atime) * 2.4 * 2); // shock absorber
    tcs.getRawData(&r, &g, &b, &c);
    break;    
  }

  // DN40 calculations
  ir = (r + g + b > c) ? (r + g + b - c) / 2 : 0;
  r_comp = r - ir;
  g_comp = g - ir;
  b_comp = b - ir;
  c_comp = c - ir;   
  cratio = float(ir) / float(c);

  saturation = ((256 - atime) > 63) ? 65535 : 1024 * (256 - atime);
  saturation75 = (atime_ms < 150) ? (saturation - saturation / 4) : saturation;
  isSaturated = (atime_ms < 150 && c > saturation75) ? 1 : 0;
  cpl = (atime_ms * againx) / (TCS34725_GA * TCS34725_DF); 
  maxlux = 65535 / (cpl * 3);

  lux = (TCS34725_R_Coef * float(r_comp) + TCS34725_G_Coef * float(g_comp) + TCS34725_B_Coef * float(b_comp)) / cpl;
  ct = TCS34725_CT_Coef * float(b_comp) / float(r_comp) + TCS34725_CT_Offset;
}

tcs34725 rgb_sensor;
//************************************************************************************************************************

// VARIABLES
uint8_t cmd;
int i;
bool connected;
int len;
uint8_t sendData[20];
uint8_t getData[20];
uint8_t last_sector_ID = 0;
uint8_t current_sector_ID = 0;

uint16_t r, g, b, color, colorTemp, lux;

// BOARD CONSTANTS
#define RED_LED_PIN   2
#define GREEN_LED_PIN 3
#define BLUE_LED_PIN  4

/* Initialise color sensor with default values (int time = 2.4ms, gain = 1x) */
// Adafruit_TCS34725 tcs = Adafruit_TCS34725();

/* Initialise color sensor with specific int time and gain values */
Adafruit_TCS34725 tcs = Adafruit_TCS34725(TCS34725_INTEGRATIONTIME_700MS, TCS34725_GAIN_1X);

// TOKEN FIRMWARE METADATA
#define NAME    "AnyBoard Pawn"
#define VERSION "0.1"
#define UUID    "3191-6275-32g4"

// COMMANDS
const uint8_t GET_NAME             = 32;
const uint8_t GET_VERSION          = 33;
const uint8_t GET_UUID             = 34;
const uint8_t HAS_LED              = 64;
const uint8_t HAS_LED_COLOR        = 65;
const uint8_t HAS_VIBRATION        = 66;
const uint8_t HAS_COLOR_DETECTION  = 67;
const uint8_t HAS_LED_SCREEN       = 68;
const uint8_t HAS_RFID             = 71;
const uint8_t HAS_NFC              = 72;
const uint8_t HAS_ACCELEROMETER    = 73;
const uint8_t HAS_TEMPERATURE      = 74;
const uint8_t LED_OFF              = 128;
const uint8_t LED_ON               = 129;
const uint8_t LED_BLINK            = 130;
const uint8_t READ_COLOR           = 136;
const uint8_t MOVE                 = 194;

void setup() {
    rgb_sensor.begin();
    
    // Enable outputs.
    pinMode(RED_LED_PIN, OUTPUT);
    pinMode(GREEN_LED_PIN, OUTPUT);
    pinMode(BLUE_LED_PIN, OUTPUT);
    
    // Turn Off all LEDs initially
    digitalWrite(RED_LED_PIN, LOW);
    digitalWrite(GREEN_LED_PIN, LOW);
    digitalWrite(BLUE_LED_PIN, LOW);

    // configure the RFduino BLE properties
    RFduinoBLE.advertisementData = "ledbtn";
    RFduinoBLE.advertisementInterval = 500;
    RFduinoBLE.deviceName = "RFduino";
    RFduinoBLE.txPowerLevel = -20;

    // start the BLE stack
    RFduinoBLE.begin();
    Serial.begin(9600);
}

// Loops and reads color. Sends signal to client if detecting a changed color
void loop() {
    rgb_sensor.getData();
    
    /*// Read color codes, based on the code in https://learn.adafruit.com/adafruit-color-sensors/programming
    tcs.getRawData(&r, &g, &b, &color);
    colorTemp = tcs.calculateColorTemperature(r, g, b);

    // Color hex translation to sector IDs
    // Sector_NAMES     Sector_ID       Color_ID (approx value given by the sensor)
    // START            1               12228
    // STOP             2               5737
    // A                3               18330
    // B                4               9560
    // C                5               8550
    // D                6               6806
    // E                7               5920
    // F                8               15454*/
    Serial.println();
    Serial.print(rgb_sensor.ct);
    Serial.println();
//    if (rgb_sensor.ct > 3765 && rgb_sensor.ct < 3950)
//    {
//      current_sector_ID = 8;
//      Serial.print("Grey");
//    }
//    else 
    if (rgb_sensor.ct > 2500 && rgb_sensor.ct < 2700)
    {
        current_sector_ID = 3;
        Serial.print("Yellow");
    }
//    else if (rgb_sensor.ct > 3800 && rgb_sensor.ct < 3850)
//    {   current_sector_ID = 7;
//        Serial.print("White");        
//    }
    else if (rgb_sensor.ct > 4350 && rgb_sensor.ct < 4550)
    {
        current_sector_ID = 4;
        Serial.print("Green");
    }
    else if (rgb_sensor.ct > 4000 && rgb_sensor.ct < 4350)
    {
        current_sector_ID = 5;
        Serial.print("Purple");
    }
//    else if (rgb_sensor.ct > 5880 && rgb_sensor.ct < 5950)
//    {
//        current_sector_ID = 1;
//        Serial.print("White blue");
//    }
    else if (rgb_sensor.ct > 5500 && rgb_sensor.ct < 6200)
    {
        current_sector_ID = 6;
        Serial.print("Dark blue");
    }
    else if (rgb_sensor.ct > 3700 && rgb_sensor.ct < 4000)
    {
        current_sector_ID = 2;
        Serial.print("Black");
    }
    else
    {
        Serial.print("Non trouve");
    }

    // Sends sectors ID of the sector that has been left and the sector that has been reached
    if (current_sector_ID != last_sector_ID) {
        sendData[0] = MOVE;
        sendData[1] = current_sector_ID;
        sendData[2] = last_sector_ID;
        RFduinoBLE.send((char*) sendData, 3);
        Serial.println();
        Serial.print("MOVE FROM ");
        Serial.print(last_sector_ID);
        Serial.print(" ");
        Serial.print(current_sector_ID); 
        // Update sector_ID variables
        last_sector_ID = current_sector_ID;
    }
    delay(300);
}

// Turns on LED
void ledOn(int r, int g, int b) {
    if (r < 127) {
        digitalWrite(RED_LED_PIN, LOW);
    } else {
        digitalWrite(RED_LED_PIN, HIGH);
    }
    if (g < 127) {
        digitalWrite(GREEN_LED_PIN, LOW);
    } else {
        digitalWrite(GREEN_LED_PIN, HIGH);
    }
    if (b < 127) {
        digitalWrite(BLUE_LED_PIN, LOW);
    } else {
        digitalWrite(BLUE_LED_PIN, HIGH);
    }
}

// Turns off LED
void ledOff() {
    ledOn(0,0,0);
}

// Blinks LED
void ledBlink(int r, int g, int b, int delayTime) {
    ledOn(r, g, b);
    delay(delayTime*10);
    ledOff();
    delay(delayTime*10);
    ledOn(r, g, b);
    delay(delayTime*10);
    ledOff();
    delay(delayTime*10);
    ledOn(r, g, b);
    delay(delayTime*10);
    ledOff();
    delay(delayTime*10);
    ledOn(r, g, b);
    delay(delayTime*10);
    ledOff();
    delay(delayTime*10);
    ledOn(r, g, b);
    delay(delayTime*10);
    ledOff();
    delay(delayTime*10);
    ledOn(r, g, b);
}

// Code that executes everytime the radio advertises
void RFduinoBLE_onAdvertisement() {
    digitalWrite(RED_LED_PIN, LOW);
    digitalWrite(GREEN_LED_PIN, LOW);
    digitalWrite(BLUE_LED_PIN, LOW);
}

// Code that executes everytime token is being connected to
void RFduinoBLE_onConnect() {
    connected = true;
}

// Code that executes everytime token is being disconnected from
void RFduinoBLE_onDisconnect() {
    connected = false;
}

// Sends data to the connected client
void send_uint8(uint8_t *data, int length) {
    char charData[length];
    for (i = 0; i < length; i++) {
        charData[i] = data[i];
    }
    RFduinoBLE.send(charData, length);
}

// Sends data (uint8 + String) to the connected client
void send_string(uint8_t command, char* string) {
    len = strlen(string);
    sendData[0] = command;
    for (i = 0; i < len; i++) {
        sendData[i+1] = string[i];
    }
    send_uint8(sendData, len+1);
}

// Code to run upon receiving data over bluetooth
void RFduinoBLE_onReceive(char *data, int length) {

    // Stores the first integer to cmd variable
    cmd = data[0];

    // Resets the incoming data array
    memset(getData, 0, sizeof(getData));

    // Stores the rest of the incoming data in getData array
    for (i = 1; i < length; i++) {
        getData[i-1] = data[i];
    }

    // Executes the command
    parse(cmd);
}

// Executes command
void parse(uint8_t command) {

    // Resets the outcoming data array
    memset(sendData, 0, sizeof(sendData));

    // Sets the command as the first data to send
    sendData[0] = command;

    switch (command) {
        case GET_NAME:
            send_string(GET_NAME, NAME);
            break;
        case GET_VERSION:
            send_string(GET_VERSION, VERSION);
            break;
        case GET_UUID:
            send_string(GET_UUID, UUID);
            break;
        case LED_ON:
            ledOn(getData[0], getData[1], getData[2]);
            send_uint8(sendData, 1);
            break;
        case LED_OFF:
            ledOff();
            send_uint8(sendData, 1);
            break;
        case LED_BLINK:
            ledBlink(getData[0], getData[1], getData[2], getData[3]);
            send_uint8(sendData, 1);
            break;
        case HAS_LED:
            sendData[1] = 1;
            send_uint8(sendData, 2);
            break;
        case HAS_LED_COLOR:
            sendData[1] = 1;
            send_uint8(sendData, 2);
            break;
        case HAS_VIBRATION:
            sendData[1] = 0;
            send_uint8(sendData, 2);
            break;
        case HAS_COLOR_DETECTION:
            sendData[1] = 1;
            send_uint8(sendData, 2);
            break;
        case HAS_LED_SCREEN:
            sendData[1] = 0;
            send_uint8(sendData, 2);
            break;
        case HAS_RFID:
            sendData[1] = 0;
            send_uint8(sendData, 2);
            break;
        case HAS_NFC:
            sendData[1] = 0;
            send_uint8(sendData, 2);
            break;
        case HAS_ACCELEROMETER:
            sendData[1] = 0;
            send_uint8(sendData, 2);
            break;
        case HAS_TEMPERATURE:
            sendData[1] = 0;
            send_uint8(sendData, 2);
            break;
        default:
            sendData[0] = 0;
            send_uint8(sendData, 1);
    }
}

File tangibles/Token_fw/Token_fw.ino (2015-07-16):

// Token's firmware working copy
// Code based on RFDUINO hardware, uses C char arrays

#include <ArduinoJson.h>
#include <RFduinoBLE.h>
#include <Wire.h>
#include "Adafruit_TCS34725.h"

int led_green = 4;
int led_red = 2;
int led_blue = 3;

//JSON test strings
char OFF[] = "{\"device\":\"LED\",\"event\":\"off\"}";
char GREEN[] = "{\"device\":\"LED\",\"event\":\"on\",\"color\":\"green\"}";
char RED[] = "{\"device\":\"LED\",\"event\":\"on\",\"color\":\"red\"}";
char BLUE[] = "{\"device\":\"LED\",\"event\":\"on\",\"color\":\"blue\"}";
char WHITE[] = "{\"device\":\"LED\",\"event\":\"on\",\"color\":\"white\"}";

/* Initialise color sensor with default values (int time = 2.4ms, gain = 1x) */
// Adafruit_TCS34725 tcs = Adafruit_TCS34725();
/* Initialise color sensor with specific int time and gain values */
Adafruit_TCS34725 tcs = Adafruit_TCS34725(TCS34725_INTEGRATIONTIME_700MS, TCS34725_GAIN_1X);

//Variable needed for colors to sector translation
uint16_t last_sector_ID = 0;

void setup() {
  Serial.begin(57600); //Streams debug messagges over the serial port DEFAULT: OFF
  pinMode(led_green, OUTPUT);
  pinMode(led_red, OUTPUT);
  pinMode(led_blue, OUTPUT);

  // Test LED on startup
  parseJSON(GREEN);
  delay(300);
  parseJSON(RED);
  delay(300);
  parseJSON(BLUE);
  delay(300);
  parseJSON(WHITE);
  delay(300);
  parseJSON(OFF);
  delay(300);

  //Initialise bluetooth
  //Give unique identifier
  RFduinoBLE.advertisementData = "PawnA";
  //Start the BLE stack
  RFduinoBLE.begin();

  //Start the color sensor
  if (tcs.begin()) {
    Serial.println("DEBUG: Color sensor sucesfully initiated");
  } else {
    Serial.println("DEBUG: Color sensor error");
    while (1);
  }
}

void loop() {

  //Read color codes, based on the code in https://learn.adafruit.com/adafruit-color-sensors/programming
  uint16_t r, g, b, color, colorTemp, lux;
  tcs.getRawData(&r, &g, &b, &color);
  colorTemp = tcs.calculateColorTemperature(r, g, b);
  Serial.print("DEBUG: Color: "); Serial.print(color, DEC); Serial.print(" ");
  Serial.println(" ");

  //Color hex translation to sector IDs
  // Sector_NAMES 	Sector_ID	                Color_ID (approx value given by the sensor)
  // START	 		1			12228
  // STOP	 		2			5737
  // A				3			18330
  // B				4			9560
  // C				5			8550
  // D				6			6806
  // E				7			5920
  // F				8			15454

   uint16_t current_sector_ID = 0;

  if (color > 12000 && color < 13000)
    current_sector_ID = 1;
  else if (color > 5300 && color < 5800)
    current_sector_ID = 2;
  else if (color > 18000 && color < 19000)
    current_sector_ID = 3;
  else if (color > 9000 && color < 10000)
    current_sector_ID = 4;
  else if (color > 8000 && color < 9000)
    current_sector_ID = 5;
  else if (color > 6500 && color < 7500)
    current_sector_ID = 6;
  else if (color > 5801 && color < 6300)
    current_sector_ID = 7;
  else if (color > 15000 && color < 16000)
    current_sector_ID = 8;


  //Sends sectors ID of the sector that has been left and the sector that has been reached in formatted JSON
  if (current_sector_ID != last_sector_ID)
  {
    String closure = "\"}";

    String sector_left = String("{\"event\":\"left\",\"SECTOR_ID\":\"" + last_sector_ID);
    sector_left = String(sector_left + closure);

    String sector_reached = String("{\"event\":\"reached\",\"SECTOR_ID\":\"" + current_sector_ID);
    sector_reached = String(sector_reached + closure);

    char payload1[34];
    char payload2[34];
    sector_left.toCharArray(payload1, 33);
    sector_reached.toCharArray(payload2, 33);
    
    RFduinoBLE.send(*payload1);
    RFduinoBLE.send(*payload2);
    
    //Update sector_ID variables
    last_sector_ID = current_sector_ID;
  }

  delay(10);
}


void RFduinoBLE_onAdvertisement()
{
}

void RFduinoBLE_onConnect()
{
}

void RFduinoBLE_onDisconnect()
{
}

void RFduinoBLE_onReceive(char *data, int len)
{
  parseJSON(data);
}

//Parses JSON messages
void parseJSON(char *payload) {
  char sel;
  // char json[200];
  // payload.toCharArray(json, 50);
  StaticJsonBuffer<200> jsonBuffer;
  JsonObject& root = jsonBuffer.parseObject(payload);

  // Serial.print("DEBUG: "); Serial.println(json);
  if (!root.success()) {
    Serial.println("parseObject() failed");
    return;
  }

  const char* device = root["device"];
  const char* event = root["event"];
  const char* color = root["color"];

  if (strcmp(device, "LED") == 0)
  {
    if (strcmp(event, "on") == 0)
    {
      sel = color[0];
      ledON(sel);
    }
    if (strcmp(event, "off") == 0)
    {
      ledOFF();
    }
  }
}

// Turns the LED off
void ledOFF() {
  digitalWrite(led_red, LOW);
  digitalWrite(led_green, LOW);
  digitalWrite(led_blue, LOW);
}

// Turns on the LED on a specific color: r=red, g=gree, osv..
void ledON(char sel) {
  switch (sel)
  {
    case 'r':
      {
        digitalWrite(led_red, HIGH);
        digitalWrite(led_green, LOW);
        digitalWrite(led_blue, LOW);
        Serial.println("DEBUG: LED RED ON");
        break;
      }
    case 'g':
      {
        digitalWrite(led_red, LOW);
        digitalWrite(led_green, HIGH);
        digitalWrite(led_blue, LOW);
        Serial.println("DEBUG: LED GREEN ON");
        break;
      }
    case 'b':
      {
        digitalWrite(led_red, LOW);
        digitalWrite(led_green, LOW);
        digitalWrite(led_blue, HIGH);
        Serial.println("DEBUG: LED BLUE ON");
        break;
      }
    case 'w':
      {
        digitalWrite(led_red, HIGH);
        digitalWrite(led_green, HIGH);
        digitalWrite(led_blue, HIGH);
        Serial.println("DEBUG: LED WITHE ON");
        break;
      }
  }
}

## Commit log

2015-10-05 added construction schematics
    [2_protoype.stl]
2016-02-18 Added printer functionality to the color quiz
    At the end of a round, a small certificate with the score is printed.
    Also changed the "ready for next question" color to purple.
2016-02-19 disabled accelerometer in pawn
2016-04-21 improved color recognition by quantisation, fixed power source-battery signal bias
2016-10-27 construction files cleanup
    [2_protoype.stl, anypawn_case_formlab.stl, anypawn_colorsensor_mask.stl]
2016-11-04 UPD: libs structure. ADD: display digit case.
2016-11-07 ADD: gitignore, anypawn case 3D model w/ support
    [anypawn_case_formlab_w_support.stl]
2016-12-06 updated rfduino driver with token protocols
2017-01-20 removed example dir, no longer functioning with current hw prototype
2017-01-21 refactoring dir structure
    [anypawn_case_formlab.stl, anypawn_case_formlab_w_support.stl, anypawn_colorsensor_mask.stl]
2017-01-24 Updated anyboard driver
2017-03-02 Improving TokenSoloEvents detection Separation of the hardware logic (Accelerometer) and the pawn logic (Events)
    Théo <theo.p-h@live.fr>
2017-03-06 Implementing a TokenSoloEvent_Handler This handler can be populated with different sensors which could be a source of TokenSoloEvents. Every Sensor has to inherit from the "TokenSoloEvent" class and 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
    /!\ For the moment due the Arduino way of building we need to set the absolute path to "protocol.h" in Accelerometer.h...
2017-03-10 Refactoring code Adding a "Handler" Layer. The BLE Handler take care of sending and receiving Events. The TokenSoloEvent_Handler handles the Accelerometer and will soon handle a Gyro The TokenConstra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
    The handlers are made to have a better isolation between main firmware work and pure hardware handling.
    Be careful to copy the needed libraries to your Arduino Library folder.
    Théo
    [TokenConstraintEvent_Handler.cpp, anypawn.ino, protocol.h]
2017-04-24 Improving specific hardware implementation - Adding new sensors (LSM9DS0, VL6180x) - Adding new drivers (Haptic, RGB_LED) - Modifying protocol for rotation events
2017-04-24 New prototype Anypawn V2
    [AnyPawnDock - CADCAM Bottom Copper.TXT.GBL, AnyPawnDock - CADCAM Bottom Silk Screen.TXT.GBO, AnyPawnDock - CADCAM Bottom Solder Resist.TXT.GBS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]
2017-04-28 Adding Color calibration files : - Excel files with Ink and Laser calibration - Labview project + labview build (.exe) to monitor pawn data
    Implementing TokenFeedback_Handler.cpp
    - RGB_LED
    - Color selection with RGB array
    - Blink with time of blink (seconds) ( = 0 --> permanent) plus blinking period (ms/10)
    - Haptic
    Vibration during a specified time in ms/10
    - Matrix
    Display custom pattern (8 bytes)
    Calibration of the color sensor for inkjet printers (20 sectors)
    Modifying library.properties to implement new functionnalities
    - LED Color
    - LED Blink
    - Matrix custom Pattern display
    - Selection between ink and laser printer
    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
    [Calibration_ColorSensor_Ink.xlsx, Calibration_ColorSensor_Laser.xlsx, Footer.SLDPRT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]
2017-05-04 Driver for the 8x8 Matrix
2017-12-28 refactoring code
    [AnyPawnDock - CADCAM Bottom Copper.TXT.GBL, AnyPawnDock - CADCAM Bottom Silk Screen.TXT.GBO, AnyPawnDock - CADCAM Bottom Solder Resist.TXT.GBS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]
2018-01-28 splitted tokens files into new repos
    [Calibration_ColorSensor_Ink.xlsx, Calibration_ColorSensor_Laser.xlsx, anypawn_case_formlab.stl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]
2018-04-22 Revert "cleanup"
    This reverts commit 9861f17fed0b57869936eb1e419d9fdc0e5c559a.
    [RFduino_token.ino]
